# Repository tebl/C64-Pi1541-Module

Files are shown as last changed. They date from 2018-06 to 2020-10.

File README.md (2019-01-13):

# PI1541 Hat
OK, so the new and shiny SD2IEC wasn't all you wanted from a lowcost floppy
emulation solution for your Commodore 64! Sure, there are other good solutions
out there for those willing and able to put a lot of money into the FPGA-based
alternatives - personally can see myself affording one of them someday, but that
needs saving up some money I don't currently have. Also, I don't want my
other retro computers to think I'm completely biased towards the Commodore-stuff
so options were needed...

Thankfully, some enterprising folks have taken it upon themselves to create a
solution based on the Raspberry Pi (3B or newer) and with some extra
modifications we all can build one. Personally I prefer clean and nice PCBs
over hacked together stuff, so away I went to make one in KiCAD. My design is
based on what the original coder of the Pi1541 software has named option B, but
given that option A assumes only one device on the serial bus I wanted something
that would work with a physical 1541 drive as well (how else am I supposed to 
backup my old rotting disks?).

For more details on the software, see https://cbm-pi1541.firebaseapp.com/ for
more details not included in my humble hobby project. The base template used as a
starting point for the RPi hat, including RPi-specific connectors, is found on
https://github.com/xesscorp/RPi_Hat_Template.

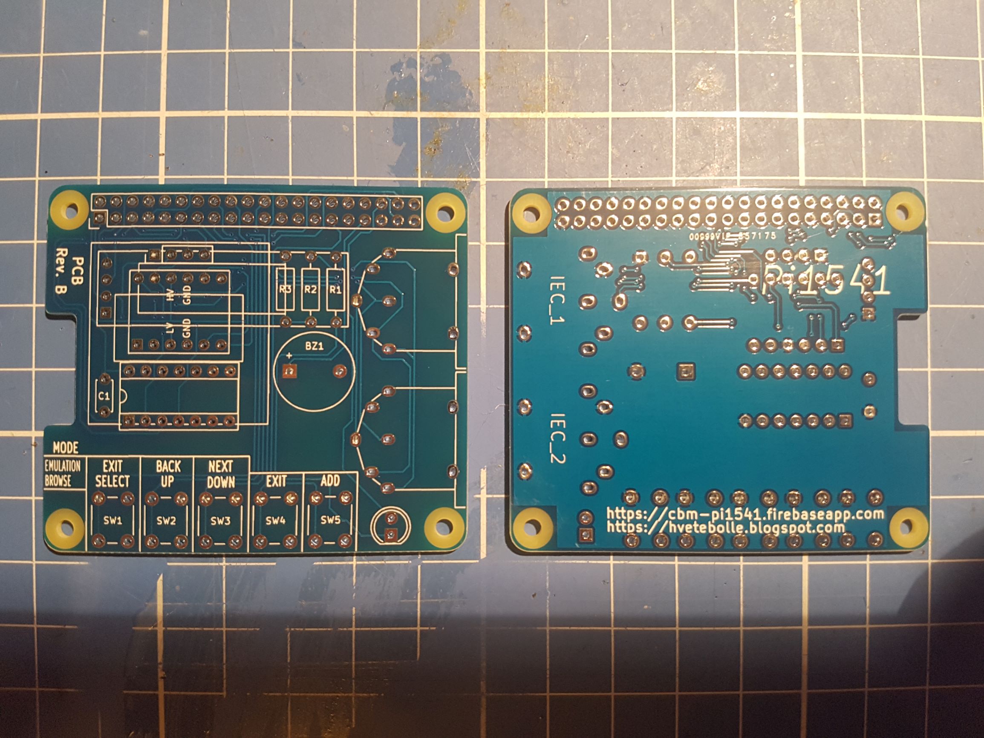
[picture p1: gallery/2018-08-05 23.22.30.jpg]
Pi1541 Revision B

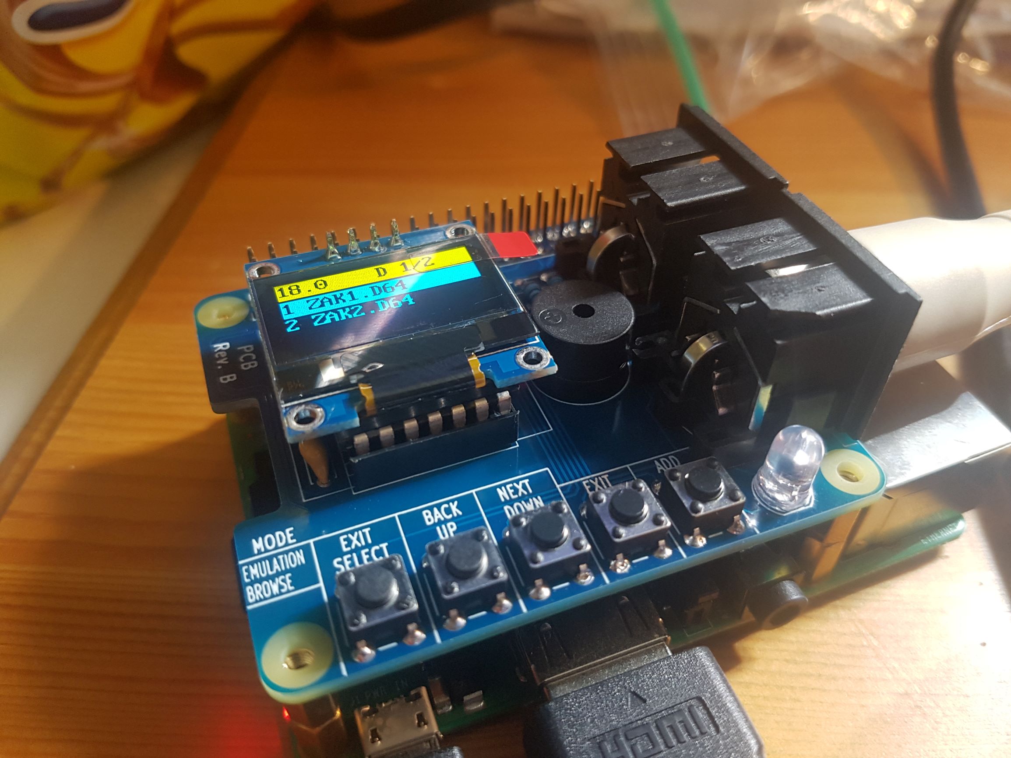
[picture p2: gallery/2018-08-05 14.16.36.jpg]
Pi1541 Installed and mounted on Raspberry Pi 3B+


# BOM
This is the part list as it stands now, everything should be readily available
from your friendly neighbourhood electronics store - for me that means ebay, but
your mileage may wary. The design of the board has been kept simple so that
anyone with access to a reasonably sized soldering iron should easily be able to
assemble it themselves, all parts are through-hole so no need to fear those tiny
SMD-parts because you won't find any of them here!

Values in parenthesis are components that are to be
considered optional, but if you want to build it for yourself I higly recommend
them as they only slightly increases the overall cost of doing this project.
Displays should be of the I2C-variety with 4 pins in the following order: GND,
VCC, SCL and SDA.

| Reference | Item | Count |
| --- | --- | ----- |
| PCB | Fabricate using Gerber files ([order](https://www.pcbway.com/project/shareproject/C64_Pi1541.html?inviteid=88707))  | 1 |
| J1 | 2x20 pin long female header | 1 |
| BZ1 | Buzzer (7mm pin spacing, 5mm OK) | (1) |
| C1 | 100nF ceramic capacitor | 1 |
| R1 | 100 Ohm resistor | 1 |
| R2, R3 | 1k Ohm resistor | 2 |
| IEC1, IEC2| Female S-terminal 6pin DIN PCB |  1 (1)|
| IC1 | SSD1306 OLED-display 128x64 (0.96") | (1)|
| IC2 | 7406 DIP | 1 |
| IC3 | 4ch I2C level converter module | 1 |
| IC4 | SSD1306 OLED-display 128x32 (0.91") | (1)|
| SW1-SW5 | Momentary push button, 6x6mm | (5)|
| D1 | 5mm LED, red for authenticity | 1 |

Please use the order link above when signing up to help me support this project, I'll get a small discount on future orders and hopefully that means I can afford to keep developing new and exciting modules in the future. By using the URL you won't have to deal with the rather daunting order forms for PCB fabrication, but if you want to go that route they'll probably want a zipped-up copy of the files in the export-directory!

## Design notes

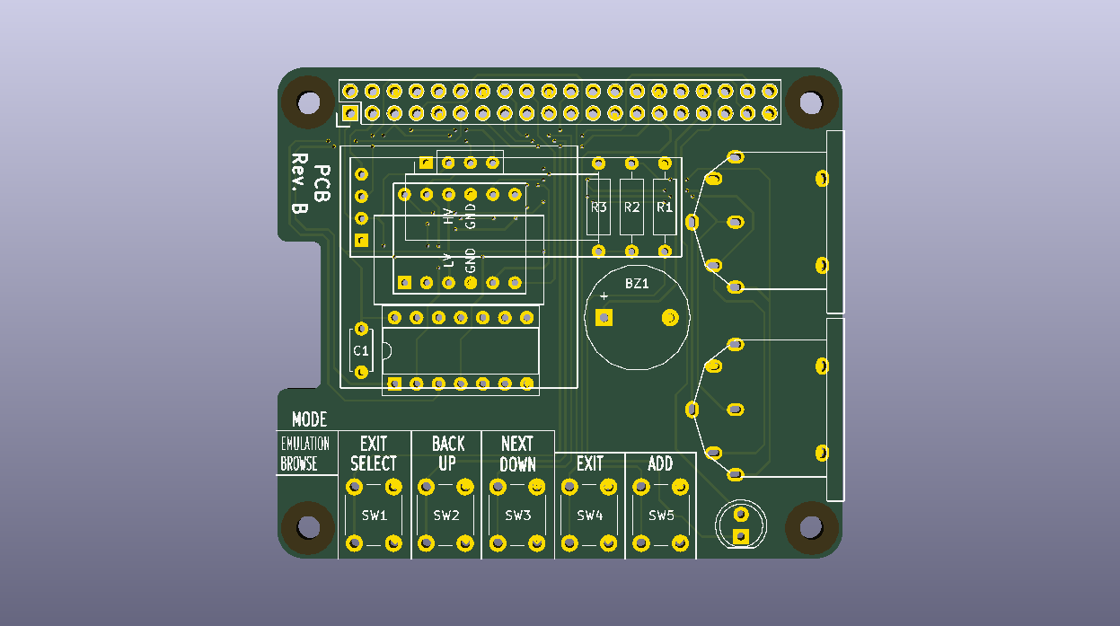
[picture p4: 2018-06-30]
export/pcb_revision_b_preview.png

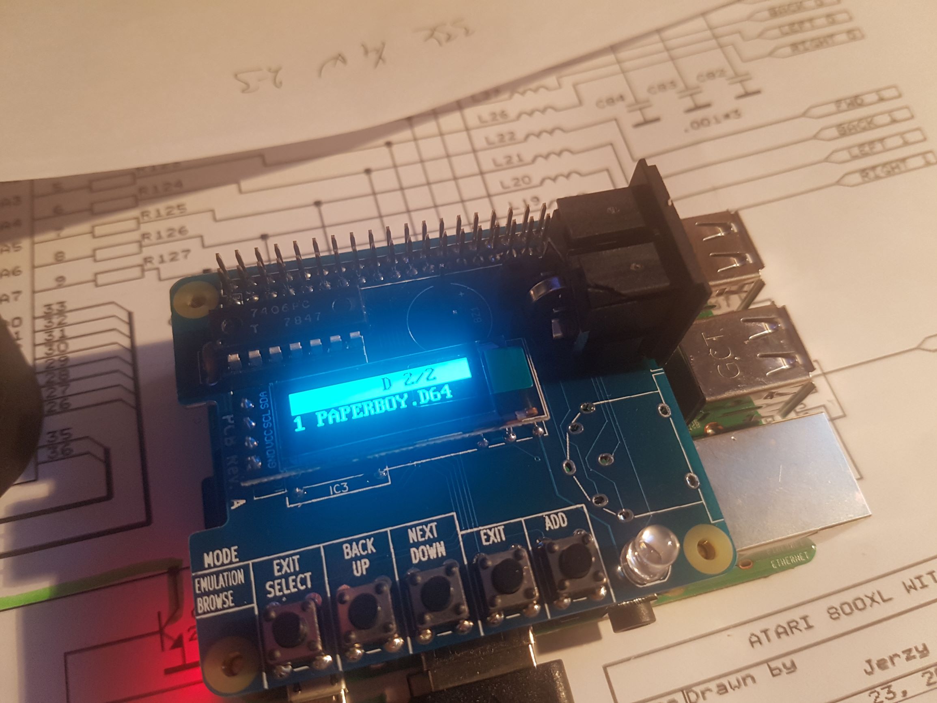
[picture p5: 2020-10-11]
gallery/2018-07-26 22.33.24.jpg

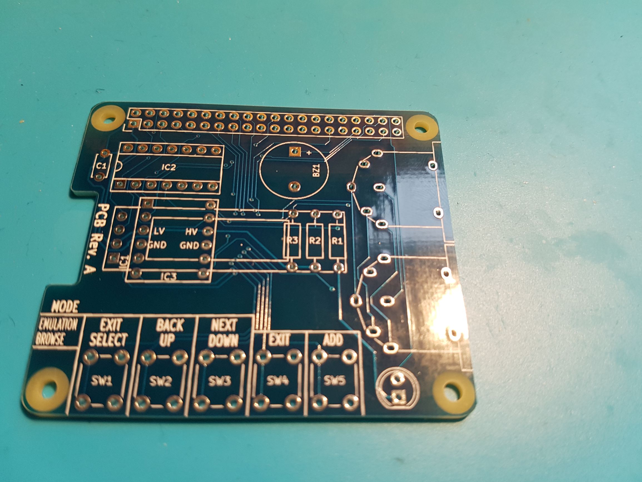
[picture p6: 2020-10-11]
gallery/2018-06-25 18.55.45.jpg

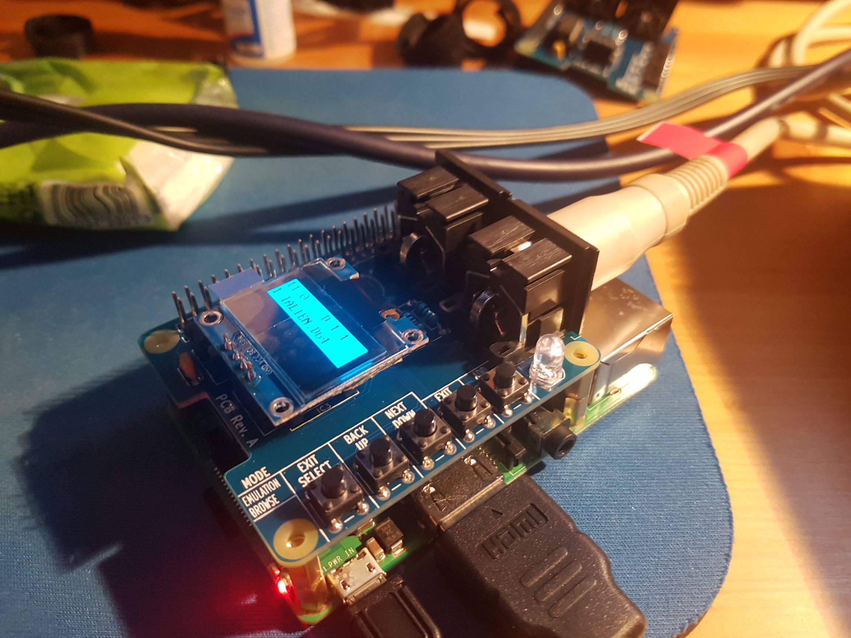
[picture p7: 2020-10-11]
gallery/2018-06-28 20.35.35.jpg

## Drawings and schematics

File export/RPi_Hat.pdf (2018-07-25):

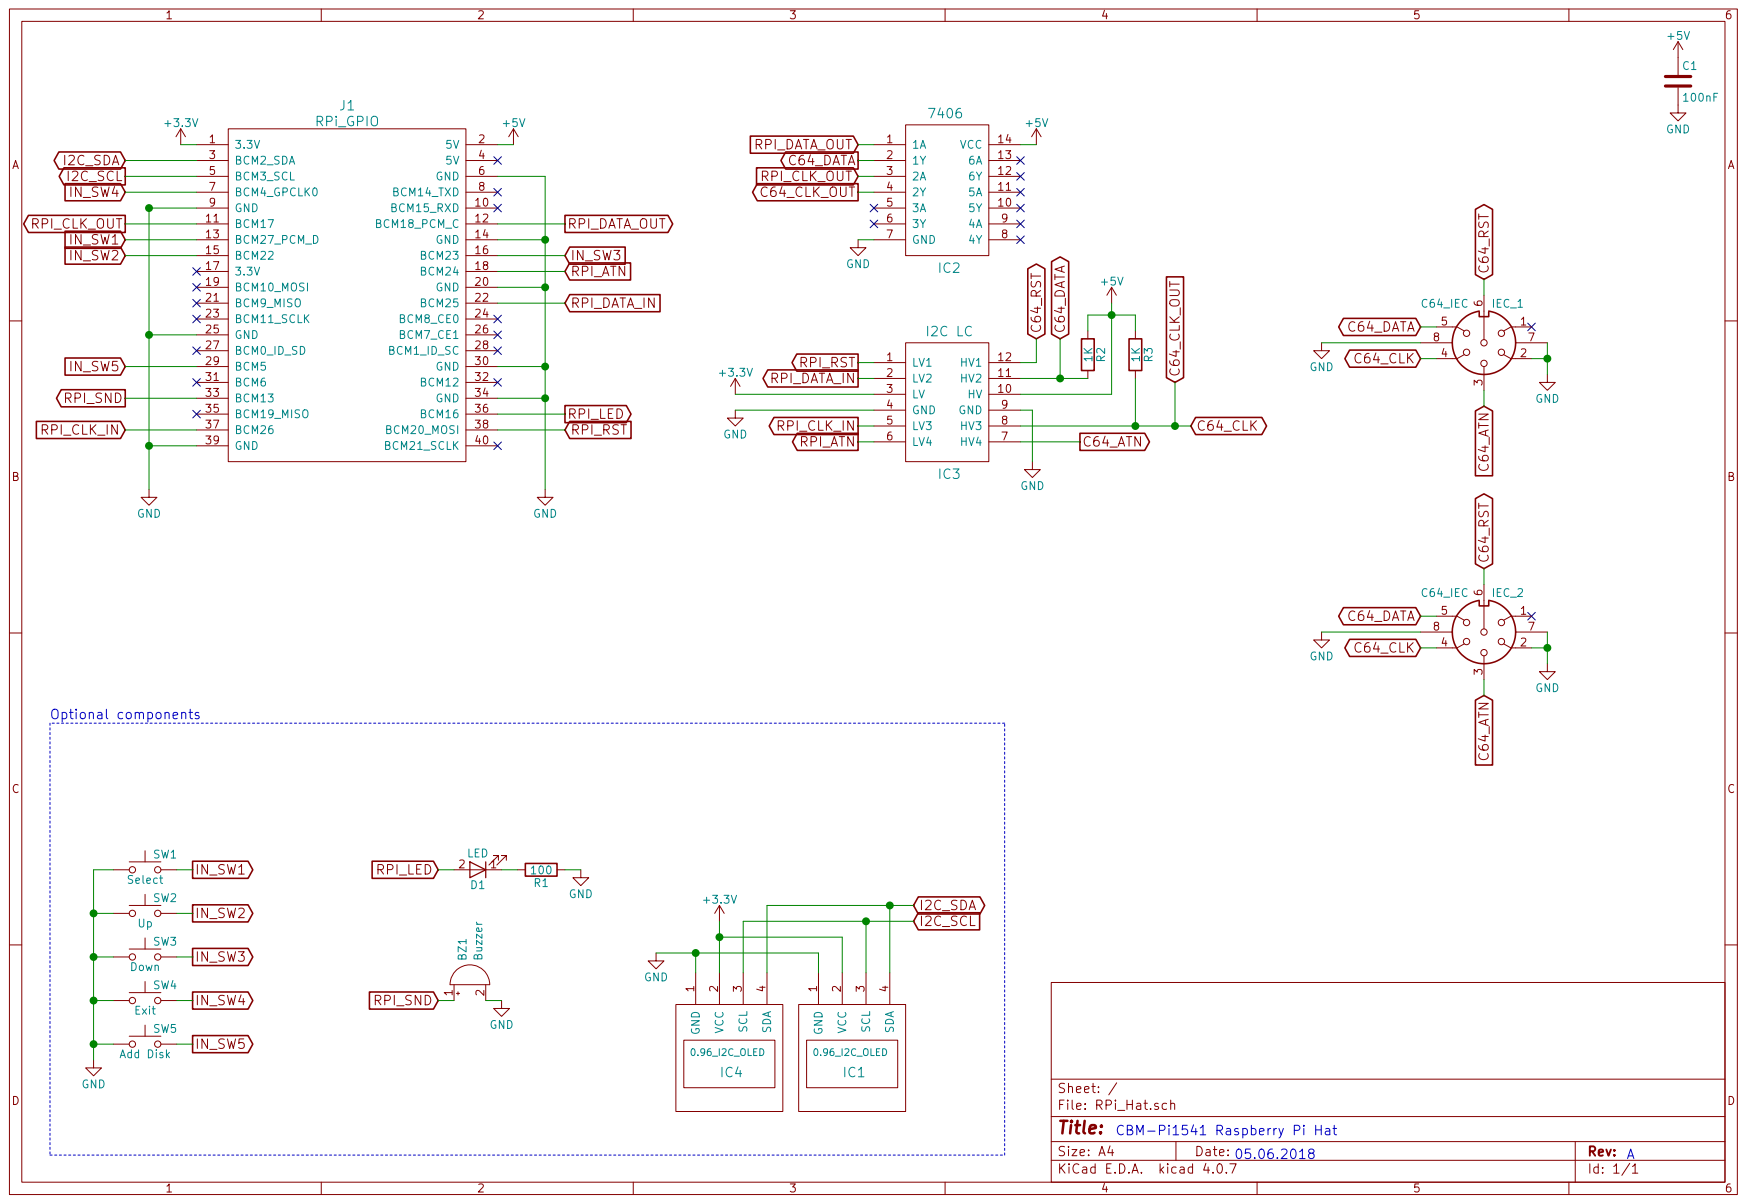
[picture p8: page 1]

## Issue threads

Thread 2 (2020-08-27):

gnd and 5v swapped on oled?

Commodore-Bench, 2020-08-27:
Ordered the latest version of this (late spring 2020) from pcbway.  What I built doesn't work.  one of the issues I think I have identified is that the 5v and ground for the oled are swapped if you use header pins.  I am going to work around this by using wires.

timpsensky, 2020-08-28:
Just a quick follow up.  I obviously meant 3.3v for the oled. Once I wired that up correctly I was able to get the PI1541 working. I had a bad 7406 that was causing other issues not related to the board layout.

tebl, 2021-12-30:
Sorry about the late follow up, I've got a bit too many projects that I seem to do and forget about, glad to see that you got it working. Regarding the OLED, various later clones have reshuffled the pins somewhat so these days it's a bit random which kind you end up getting. I've incorporated this into the later C64 Pi1541-II project.

Closed 2021-12-30.

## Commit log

2018-06-05 Empty through hole template
    [RPi_GPIO.sch, RPi_Hat.kicad_pcb, RPi_Hat.sch]
2018-06-05 Added components to schematic
    [RPi_GPIO.sch, RPi_Hat.kicad_pcb, RPi_Hat.sch]
2018-06-06 Added optional display with jumpers to handle differences in power pins
    [RPi_Hat.sch]
2018-06-06 OLED footprint
    [RPi_Hat.sch]
2018-06-12 Added I2C Level Converter
    [RPi_Hat.sch]
2018-06-12 Added IEC footprint
    [RPi_Hat.sch]
2018-06-12 Schematic completed
    [RPi_Hat.sch]
2018-06-12 Layed out PCB
    [RPi_Hat.kicad_pcb, RPi_Hat.sch]
2018-06-12 Added silkscreen info.
    [RPi_Hat.kicad_pcb]
2018-06-12 Export revision A
    [RPi_Hat-B.Cu.gbl, RPi_Hat-B.Mask.gbs, RPi_Hat-B.Paste.gbp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]
2018-06-14 Revision A as sent to fab.
    [RPi_Hat-B.Cu.gbl, RPi_Hat-B.Mask.gbs, RPi_Hat-B.Paste.gbp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]
2018-06-29 Revision B PCB layout
    [RPi_Hat.kicad_pcb, RPi_Hat.sch]
2018-06-30 Revision B gerber export
    [RPi_Hat-B.Cu.gbl, RPi_Hat-B.Mask.gbs, RPi_Hat-B.Paste.gbp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]
2018-07-25 Added schematic export
2018-08-23 Added BOM to README
2018-08-23 BOM had wrong references for some components
2018-08-23 Forgot the LED :-(
2018-10-02 Bumped revision number
    [RPi_Hat.kicad_pcb]
2018-10-02 Gerber export
    [RPi_Hat-B.Cu.gbl, RPi_Hat-B.Mask.gbs, RPi_Hat-B.Paste.gbp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]
